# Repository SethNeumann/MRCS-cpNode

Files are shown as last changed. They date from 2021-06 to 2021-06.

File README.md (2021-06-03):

# MRCS-cpNode
## License: Creative Commons Attribution-NonCommercial-ShareAlike

cpNode and I/O expander (IOX) boards have been updated to version
2.6. Based on customer feedback, and our design and installation
experience, the changes were made to provide more efficient and
flexible physical layout of some components.

  * Rev 2.6 boards are 100% backward compatible with current versions. No software changes are needed.

Version 2.6 brings the following improvements to the proven cpNode design:

  * CMRInet interface connection has been made consistent with five position pads (R+, R-,T+,T-,SHLD).for 3.5mm screw terminals, we've removed some rarely used configurations
  * Input/Output pads moved .2" back from edge for better DIN rail clearance. The I/O option pad area accepts standard DIP component headers with 0.4" pad spacing.
  * Gnd/LED Com pads aligned to .1" (2.54 mm) for a screw terminal block or male header pins
  * Removed rarely ordered on board stall motor driver option

What does a cpNode do?

cpNodes provide input and output (I/O) ports which connect to LEDs
for signals, push buttons, turnout motors, block detectors, and
other devices to a central computer for controlling model railroads.
cpNodes may also be used as standalone controllers for staging,
crossings and interlocking plants.

You must provide a Bread Board Leonardo (BB-Leo) processor, available
from Modern Device, use coupon code "cpnode"  (DO NOT order the
header kit as headers for the BB-Leo are included in all assembled
cpNode configurations.) or order the "cpNode 2.5 LE" which includes
the BB-Leo

A cpNode has:

  * 16 I/O lines with solder pads for LED limiting resistors
  * Screw terminal blocks or solder pads to connect external devices - see configurations below
  * CMRInet RS-422/485 Network Interface.  CMRInet is now NMRA Layout Control Specification S9-10
  * I2C interface for adding Input/Output Expander (IOX) boards for more i/o ports
  * All the i/o needed to control one end of a CTC siding, just add signals and detectors and switch motor drivers
  * Female headers to receive a BB-Leo (Arduino) processor available from Modern Device, use coupon code "cpnode" or order the cpNode LE option
  * I/O is configured in 8 bit groups, providing up to 144 lines when fully expanded with IOX16s and/or IOX32s
  * Use cpNodes as small, economical, CMRI nodes as is or customize the code to support applications requiring local intelligence
  * BB-Leo uses the Atmel Atmega32u4 processor chip, see the data sheet for electrical characteristics
  * Standard "Sketch" (Arduino program) is compatible with JMRI or traditional CMRI BASIC/Visual Basic development tools

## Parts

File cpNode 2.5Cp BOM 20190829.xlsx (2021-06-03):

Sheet: General Bom
Qty | Value | Device | Package | Parts | Description | MF | MPN | Jameco | Newark | Digikey | quan | have | need | order
1 | Green | LED3MM | LED3MM | TX | Green LED | Asian |  |  |  |  | 20 | 100 | 0
1 |  | M02 lock | 2 pos 0.100 | GND | ground & LED COM Screw terminal | Amazon |  |  |  |  | 20 | 20 | 0
1 |  | M06SIP | 1X06 | NH2 | Header 6 - for BB-Leo | Pololu | 1016 |  |  |  | 20 | 8 | 12
2 |  | M081X08 | 1X08 | IO1, IO2 | 8 pos 0.100 screw terminal | Amazon |  |  |  |  | 40 | 100 | 0
1 |  | PINHD-1X4/90 | 1X04/90 | I2CHDR | 4 Pos HEADER, buy in 40 pin breakaway |  |  |  |  |  | 20 | 100 | 0
1 | 12K | RESISTORPTH-1/2W | AXIAL-0.5 | R1 | Resistor |  |  |  |  |  | 20 | 20 | 0
1 | 470 | RESISTORPTH-1/2W | AXIAL-0.5 | R2 | Resistor |  |  |  |  |  | 20 | 1000 | 0
1 | 0.1uF | CAPPTH1 | CAP-PTH-5MM | C1 | Capacitor, ceramic |  |  |  |  |  | 20 | 20 | 0
4 | .01uF | CAPPTH1 | CAP-PTH-SMALL2 | C2, C3, C4, C5 | Capacitor, monolithic |  |  |  |  |  | 80 | 120 | 0
1 | 1N4148 | 1N914 | DO35-10 | D1 | DIODE |  |  |  |  |  | 20 | 100 | 0
2 | CMRINET-TOP-3.5MM | CMRINET-TOP-3.5MM | CMRINET-TOP-3.5MM | CMRINETTOP | CMRINet Top 3.5mm Screw Terminal 5 pos | OnShore |  | 2094506 |  | ‎OSTTE050161 (https://www.digikey.com/product-detail/en/on-shore-technology-inc/OSTTE050161/ED2638-ND/614587) | 40 | 20 | 20
1 | M04X2 | M04X2 | 2X4 | NH3 | .1 header, two rows of four - for BB-Leo |  |  |  |  |  | 20 | 100 | 0
1 | M16PTH | M16PTH | 1X16 | NH1 | 16 Arduino Header for BB-Leo | Pololu | 1031 |  |  |  | 20 | 13 | 7
2 | 1x16 | SIP 16 machine tool round socket | 1x16 | IO1,2 | SIP 16 machine tool round socket | asian |  |  |  |  | 40 | 28 | 12
1 | MAX489 | MAX489 | DIL14 | U1 | +5V, Fail-Safe, 40Mbps, Profibus RS-485/RS-422 Transceivers |  | MAX489 |  |  |  | 20 | 100 | 0
1 | NE555P | NE555P | DIL-08 | U2 | General purpose bipolar Timer | Arrow Electronics | NE555N |  | 1467742 |  | 20 | 100 | 0
2 | 16 pin SIP | 16 pin SIP machined female | SIL16 |  | SIL16 |  |  |  |  |  | 40 | 100 | 0
1 | Board | cpNode 2.5 |  |  |  | Seeed/JLC |  |  |  |  | 20 | 19 | 1
1 | socket |  | DIL14 |  |  |  |  |  |  |  | 20 | 100 | 0
1 | socket |  | DIL8 |  |  |  |  |  |  |  | 20 | 100 | 0
 | Quantity needed | 20 | 2019-08-18

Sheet: Build BOM
Qty | Value | Device | Package | Parts | Description | vendor | VPN | Unit | Extd | EOQ | Newark | Digikey | quan | #REF! | have | need
1 | Green | LED3MM | LED3MM | TX | Green LED | eBay |  | 0.01 | 0.01 | 100 |  |  | 20 | #REF! | 100 | 0
1 |  | M02 lock | 2 pos 0.100 | GND | ground & LED COM Screw terminal | Amazon |  | 0.30 | 0.30 | 50 |  |  | 20 | #REF! | 20 | 0
1 |  | M06SIP | 1X06 | NH2 | Header 6 - for BB-Leo | eBay |  | 0.07 | 0.07 | 50 |  |  | 20 | #REF! | 8 | 12
2 |  | M081X08 | 1X08 | IO1, IO2 | 8 pos 0.100 screw terminal | Amazon |  | 0.80 | 1.60 | 50 |  |  | 40 | #REF! | 100 | 0
1 |  | PINHD-1X4/90 | 1X04/90 | I2CHDR | 4 Pos HEADER, buy in 40 pin breakaway | Banggood |  | 0.04 | 0.04 | 500 |  |  | 20 | #REF! | 100 | 0
1 | 12K | RESISTORPTH-1/2W | AXIAL-0.5 | R1 | Resistor | Digikey |  | 0.02 | 0.02 | 100 |  |  | 20 | #REF! | 20 | 0
1 | 470 | RESISTORPTH-1/2W | AXIAL-0.5 | R2 | Resistor | Digikey |  | 0.02 | 0.02 | 100 |  |  | 20 | #REF! | 1000 | 0
1 | 0.1uF | CAPPTH1 | CAP-PTH-5MM | C1 | Capacitor, ceramic | eBay |  | 0.15 | 0.15 | 100 |  |  | 20 | #REF! | 20 | 0
4 | .01uF | CAPPTH1 | CAP-PTH-SMALL2 | C2, C3, C4, C5 | Capacitor, monolithic | Jameco | 25507 | 0.10 | 0.40 | 100 |  |  | 80 | #REF! | 120 | 0
1 | 1N4148 | 1N914 | DO35-10 | D1 | DIODE | Digikey | 1N914FS-ND | 0.04 | 0.04 | 100 |  |  | 20 | #REF! | 100 | 0
2 | CMRINET-TOP-3.5MM | CMRINET-TOP-3.5MM | CMRINET-TOP-3.5MM | CMRINETTOP | CMRINet Top 3.5mm Screw Terminal 5 pos | Digikey | ED2638-ND‎ | 0.75 | 1.50 | 100 |  |  | 40 | #REF! | 20 | 20
1 | M04X2 | M04X2 | 2X4 | NH3 | .1 header, two rows of four - for BB-Leo | Amazon |  | 0.19 | 0.19 | 100 |  |  | 20 | #REF! | 100 | 0
1 | M16PTH | M16PTH | 1X16 | NH1 | 16 Arduino Header for BB-Leo | Pololu | 1031 | 0.63 | 0.63 | 100 |  |  | 20 | #REF! | 13 | 7
2 | 16 pin SIP | 16 pin SIP machined female | SIL16 | 0 | buy in 40 pin breakaway | Bangood |  | 1.50 | 3.00 | 20 | 0 |  | 40 | #REF! | 100 | 0
1 | Board | cpNode 2.5 |  |  | Circuit Board - 69 x 100 mm | MRCS |  | 2.00 | 2.00 | 10 | 0 |  | 20 | #REF! | 19 | 1
1 | socket | 0 | DIL14 |  | 14 pin DIP socket | Jameco | 112214 | 0.12 | 0.12 | 100 | 0 |  | 20 | #REF! | 100 | 0
1 | socket | 0 | DIL8 |  | 8 Pin DIP Socket | Banggood |  | 0.04 | 0.04 | 50 | 0 |  | 20 | #REF! | 100 | 0
1 | BB-LEO | BB-LEO | BB-LEO |  | Arduino in BB-Leo Form Factor | Modern Device |  | 26.00 | 26.00 | 10
 |  |  |  |  |  | BOM Cost |  |  | 36.13
 | note that I am working on a board that uses a commodity Arduino ProMini which will save about $20 off the BB-Leo so the ProMini version will be about $16.50

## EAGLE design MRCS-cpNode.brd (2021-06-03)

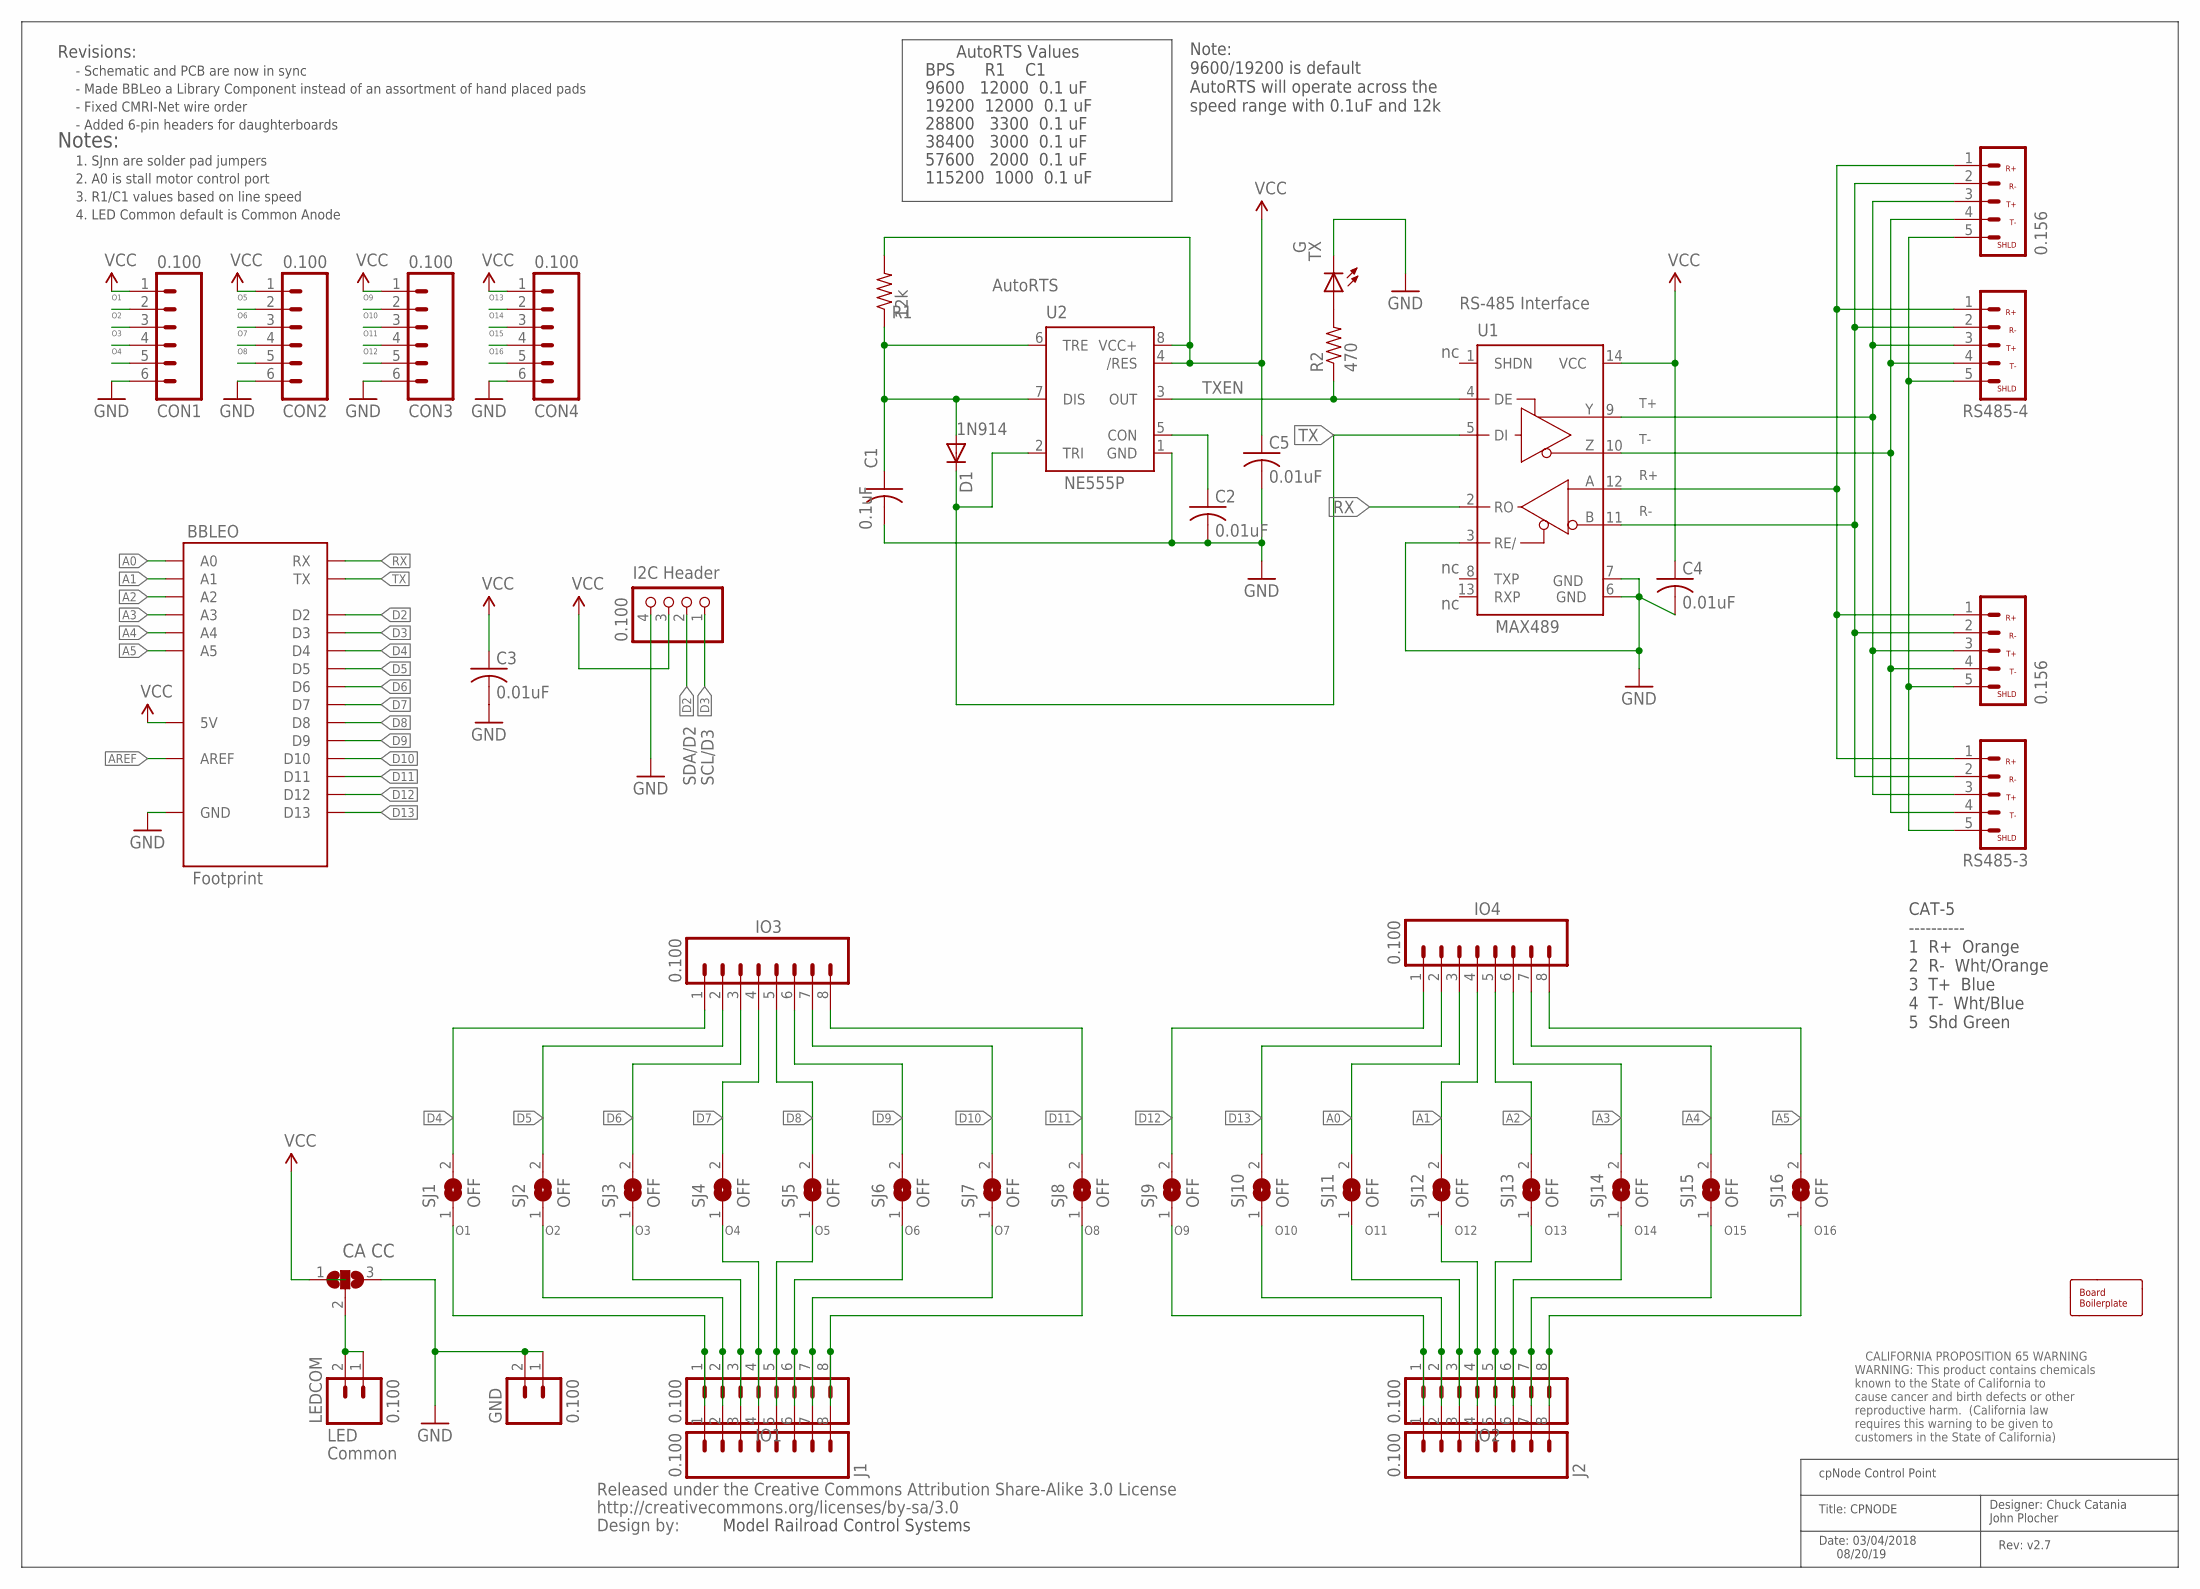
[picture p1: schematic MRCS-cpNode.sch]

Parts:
BBLEO: Footprint; ARDUINO-BBLEO
BOARD1: BOARD; BOARD-DINRAIL-2.71IN-MRCS
C1: 0.1uF; C-PTH-0.100
C2, C3, C4, C5: 0.01uF; C-PTH-0.100
CON1, CON2, CON3, CON4: 0.100; 1X06-SIP_LOCK
D1: 1N4148; DIODE-1N4148
GND: 0.100; MOLEX-1X2_LOCK
I2CHDR: 0.100; 1X04/90
IO1, IO2, IO3, IO4: 0.100; 1X08
J1, J2: 0.100; 1X08_LOCK_LONGPADS
LEDCOM: 0.100; MOLEX-1X2_LOCK
P1: CA CC; 3P-SMD-2X4.8
R1: 12k; AXIAL-0.4-RES
R2: 470; AXIAL-0.4-RES
RS485-1, RS485-2: 0.156; KK-156-5
RS485-3, RS485-4: 3.5mm; CMRINET-3.5MM
SJ1, SJ2, SJ3, SJ4, SJ5, SJ6, SJ7, SJ8, SJ9, SJ10, SJ11, SJ12, SJ13, SJ14, SJ15, SJ16: OFF; SJ
TX: G; LED3MM
U1: MAX3465CPD; DIL14
U2: NE555P; DIL-08
U$1: CREATIVE_COMMONS
U$2: Prop65; CA-PROP65WARNING

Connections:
A0: BBLEO.A0, IO4.3, SJ11.2
A1: BBLEO.A1, IO4.4, SJ12.2
A2: BBLEO.A2, IO4.5, SJ13.2
A3: BBLEO.A3, IO4.6, SJ14.2
A4: BBLEO.A4, IO4.7, SJ15.2
A5: BBLEO.A5, IO4.8, SJ16.2
AREF: BBLEO.AR (AREF)
D2: BBLEO.SDA (D2), I2CHDR.2
D3: BBLEO.SCL (D3), I2CHDR.1
D4: BBLEO.D4, IO3.1, SJ1.2
D5: BBLEO.D5, IO3.2, SJ2.2
D6: BBLEO.D6, IO3.3, SJ3.2
D7: BBLEO.D7, IO3.4, SJ4.2
D8: BBLEO.D8, IO3.5, SJ5.2
D9: BBLEO.D9, IO3.6, SJ6.2
D10: BBLEO.D10, IO3.7, SJ7.2
D11: BBLEO.D11, IO3.8, SJ8.2
D12: BBLEO.D12, IO4.1, SJ9.2
D13: BBLEO.D13, IO4.2, SJ10.2
GND: BBLEO.GND@0 (GND), BBLEO.GND@1 (GND), BBLEO.GND@2 (GND), BBLEO.GND@3 (GND), BBLEO.GND@4 (GND), C1.2, C2.2, C3.2, C4.2, C5.2, CON1.6, CON2.6, CON3.6, CON4.6, GND.1, GND.2, I2CHDR.4, P1.3, TX.K (C), U1.3 (RE/), U1.6 (GND), U1.7 (GND), U2.1 (GND)
unnamed: R2.P$2 (2), TX.A
unnamed: C2.1, U2.5 (CON)
unnamed: LEDCOM.1, LEDCOM.2, P1.2
unnamed: C1.1, D1.A, R1.P$1 (1), U2.6 (TRE), U2.7 (DIS)
unnamed: R2.P$1 (1), U1.4 (DE), U2.3 (OUT)
O1: CON1.2, IO1.1, J1.1, SJ1.1
O2: CON1.3, IO1.2, J1.2, SJ2.1
O3: CON1.4, IO1.3, J1.3, SJ3.1
O4: CON1.5, IO1.4, J1.4, SJ4.1
O5: CON2.2, IO1.5, J1.5, SJ5.1
O6: CON2.3, IO1.6, J1.6, SJ6.1
O7: CON2.4, IO1.7, J1.7, SJ7.1
O8: CON2.5, IO1.8, J1.8, SJ8.1
O9: CON3.2, IO2.1, J2.1, SJ9.1
O10: CON3.3, IO2.2, J2.2, SJ10.1
O11: CON3.4, IO2.3, J2.3, SJ11.1
O12: CON3.5, IO2.4, J2.4, SJ12.1
O13: CON4.2, IO2.5, J2.5, SJ13.1
O14: CON4.3, IO2.6, J2.6, SJ14.1
O15: CON4.4, IO2.7, J2.7, SJ15.1
O16: CON4.5, IO2.8, J2.8, SJ16.1
R+: RS485-1.1, RS485-2.1, RS485-3.1, RS485-4.1, U1.12 (A)
R-: RS485-1.2, RS485-2.2, RS485-3.2, RS485-4.2, U1.11 (B)
RX: BBLEO.RX, U1.2 (RO)
SHIELD: RS485-1.5, RS485-2.5, RS485-3.5, RS485-4.5
T+: RS485-1.3, RS485-2.3, RS485-3.3, RS485-4.3, U1.9 (Y)
T-: RS485-1.4, RS485-2.4, RS485-3.4, RS485-4.4, U1.10 (Z)
TX: BBLEO.TX, D1.C, U1.5 (DI), U2.2 (TRI)
VCC: BBLEO.+5V@1 (5V), BBLEO.+5V@2 (5V), BBLEO.+5V@3 (5V), BBLEO.+5V@4 (5V), C3.1, C4.1, C5.1, CON1.1, CON2.1, CON3.1, CON4.1, I2CHDR.3, P1.1, R1.P$2 (2), U1.14 (VCC), U2.4 (/RES), U2.8 (VCC+)

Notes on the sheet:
Rev: v2.7
Date: 03/04/2018 08/20/19
Title: CPNODE
cpNode Control Point
Designer: Chuck Catania John Plocher
SDA/D2
SCL/D3
TXEN
LED
1N914
MAX489
RS-485 Interface
Notes:
1. SJnn are solder pad jumpers
2. A0 is stall motor control port
I2C Header
3. R1/C1 values based on line speed
AutoRTS
AutoRTS Values
9600 12000 0.1 uF
19200 12000 0.1 uF
38400 3000 0.1 uF
57600 2000 0.1 uF
115200 1000 0.1 uF
BPS R1 C1
Common
4. LED Common default is Common Anode
Model Railroad Control Systems
Revisions:
CAT-5 ---------- 1 R+ Orange 2 R- Wht/Orange 3 T+ Blue 4 T- Wht/Blue 5 Shd Green
28800 3300 0.1 uF
Note: 9600/19200 is default AutoRTS will operate across the speed range with 0.1uF and 12k
- Fixed CMRI-Net wire order
- Schematic and PCB are now in sync
- Made BBLeo a Library Component instead of an assortment of hand placed pads
- Added 6-pin headers for daughterboards

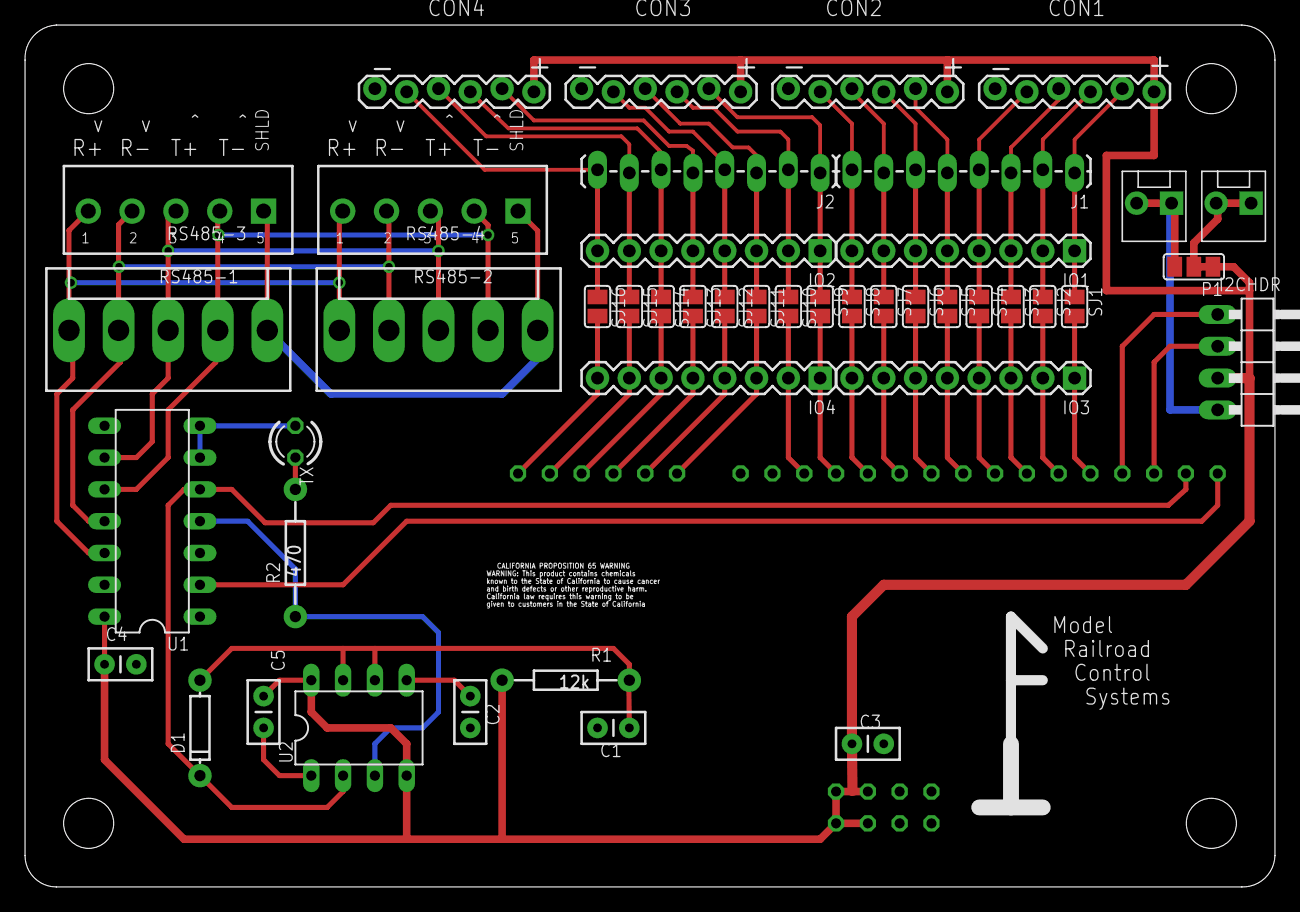
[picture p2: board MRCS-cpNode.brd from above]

Board: 2 copper layers, 99.8 x 68.8 mm, 50 parts (0 on the bottom side), 48 nets.

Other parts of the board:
U$3: MRCS; MRCS-LOGO

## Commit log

2019-11-30 updated context
    [cpNode.brd, cpNode.sch]
2019-12-09 project file names must be same as repo name
    [MRCS-cpNode.brd, MRCS-cpNode.sch]
2020-01-22 added 6-pin headers, fixed DCR errors
    [MRCS-cpNode.brd, MRCS-cpNode.sch]
2020-10-05 added missing values
    [MRCS-cpNode.brd, MRCS-cpNode.sch]
2020-10-06 normalized values
    [MRCS-cpNode.brd, MRCS-cpNode.sch]
2021-03-02 rebuilding this repository
    added BOM and the last successful zip file
    [cpNode 2.5Cp BOM 20190829.xlsx]
2021-06-03 silk and trace cleanup
    [MRCS-cpNode.brd, MRCS-cpNode.sch]

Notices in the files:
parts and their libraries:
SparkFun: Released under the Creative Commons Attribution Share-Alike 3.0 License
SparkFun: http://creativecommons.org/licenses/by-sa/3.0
